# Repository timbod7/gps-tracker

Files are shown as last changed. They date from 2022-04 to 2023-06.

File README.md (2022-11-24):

A prototype GPS tracker and interface, intended primarily as an on-water speed display.

The [firmware](firmware) is written in rust. A water resistant enclosure is used with various 3d printed components. In order to ensure water resistance, the external switches magnetically couple to internal reed switches.

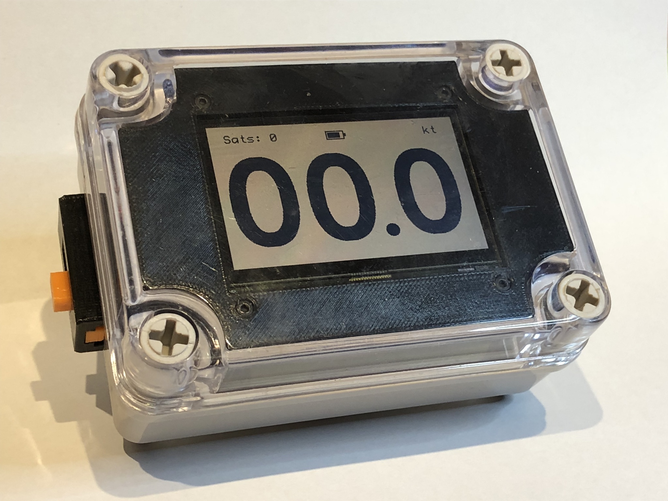
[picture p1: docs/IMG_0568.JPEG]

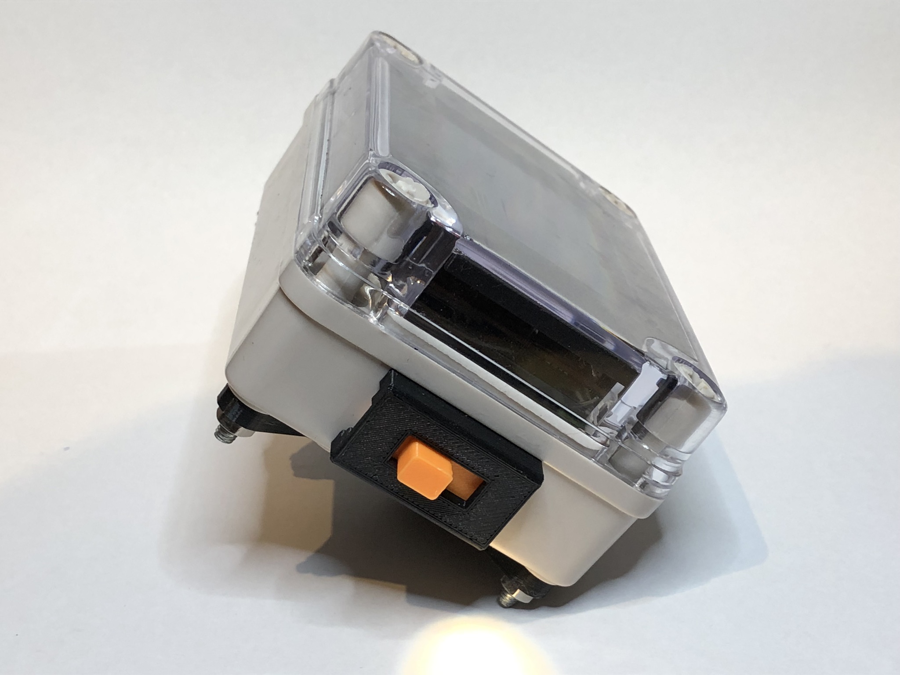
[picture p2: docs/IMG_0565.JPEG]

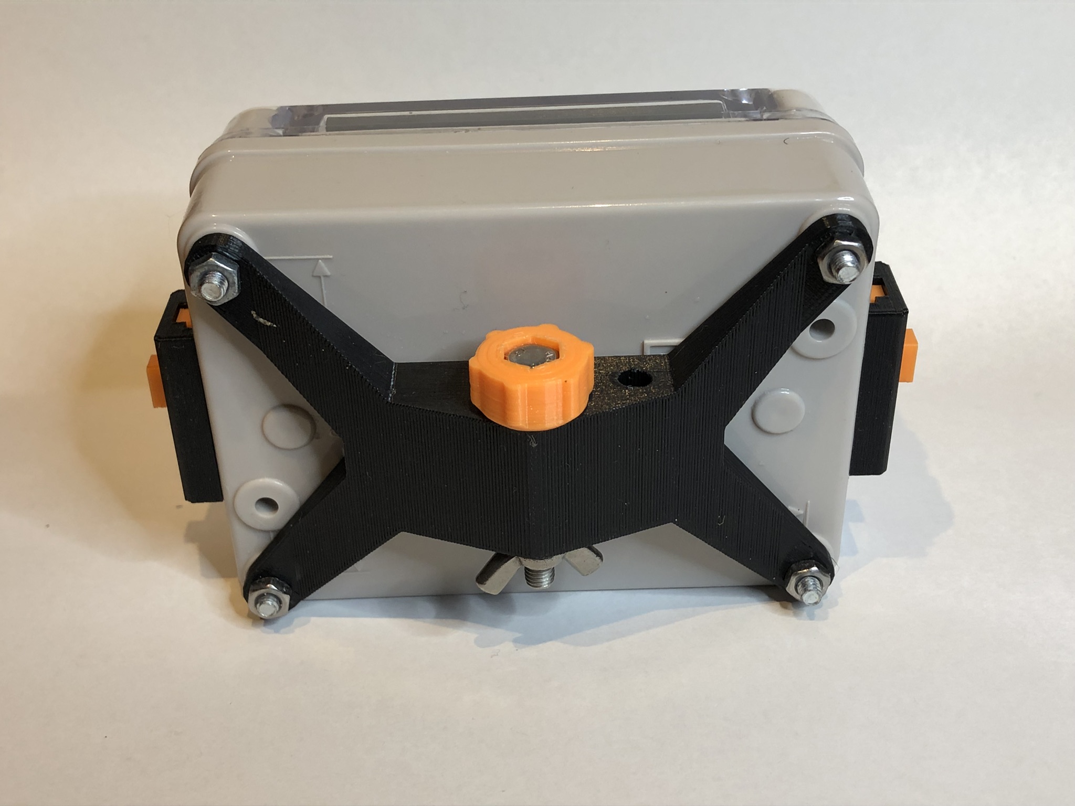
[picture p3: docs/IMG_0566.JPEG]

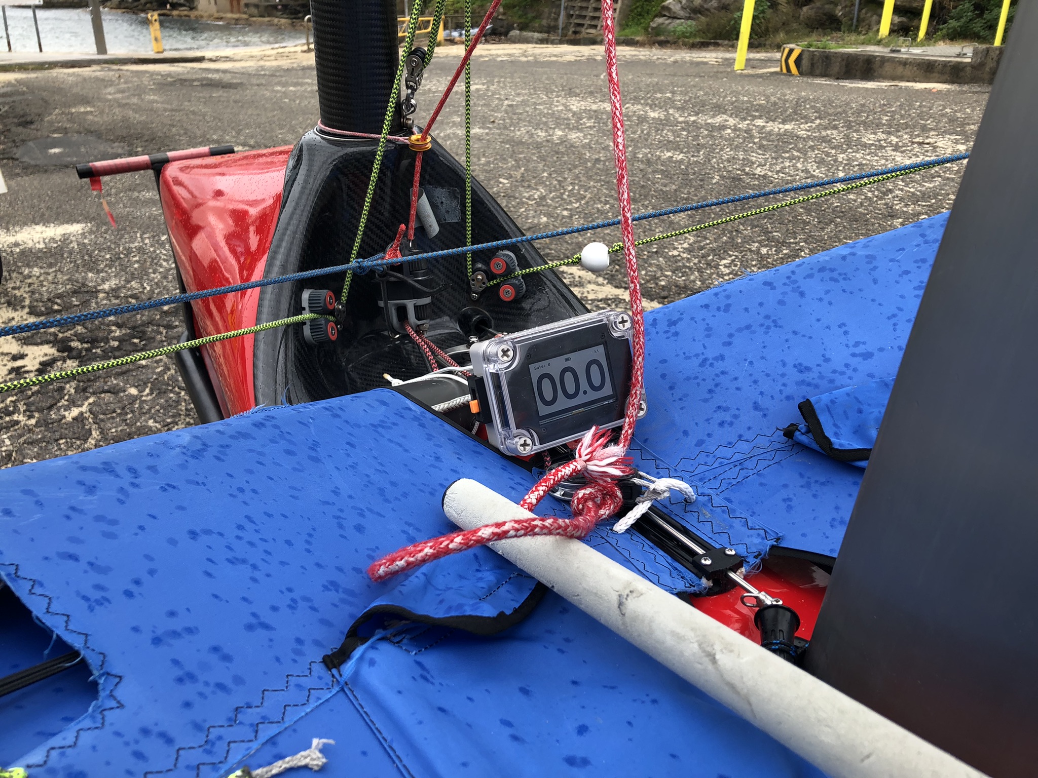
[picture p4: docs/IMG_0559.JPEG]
Installed


# Schematic

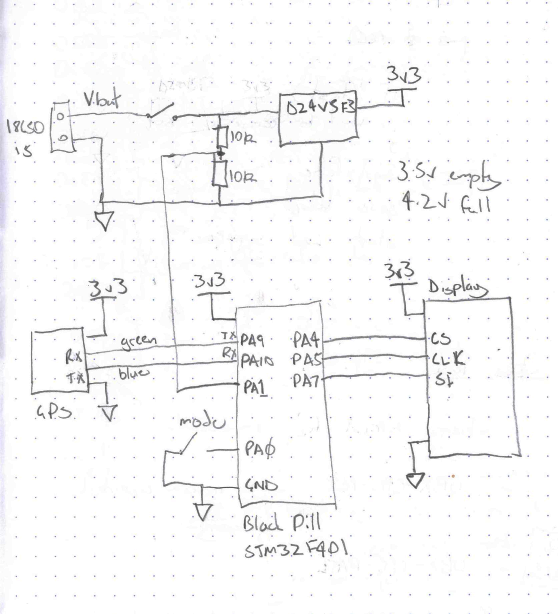
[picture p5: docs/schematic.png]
Schematic


# Components

## "Black Pill" STM32F411 board

https://core-electronics.com.au/stm32f411-blackpill-development-board-49034.html

## 3.3V LDO Regulator

https://core-electronics.com.au/pololu-3-3v-500ma-step-down-voltage-regulator-d24v5f3.html

## LS027B7DH01 LCD display 

https://core-electronics.com.au/adafruit-sharp-memory-display-breakout-2-7-400x240-monochrome.html

https://www.sharpsde.com/fileadmin/products/Displays/2016_SDE_App_Note_for_Memory_LCD_programming_V1.3.pdf

## GPS Receiver

[TBS M8.2 GPS Glonass][gps1]  (BN180 clone?)

## Waterproof Case

https://core-electronics.com.au/small-plastic-project-enclosure-weatherproof-with-clear-top.html

[gps1]: https://www.team-blacksheep.com/products/prod:tbs_m82_gps

# Firmware

To build the code, you need the `thumbv7em-none-eabihf` rust target:

```
rustup target add thumbv7em-none-eabihf
```

and cargo embed:

```
cargo install cargo-embed
```

On linux, add udev rules to ensure the stmlink device is accessible to all users:

```
$ cat /etc/udev/rules.d/50-stm-stlink.rules 
# STMicroelectronics ST-LINK/V2 
ATTRS{idVendor}=="0483", ATTRS{idProduct}=="3748", TAG+="uaccess"
$ sudo udevadm control --reload-rules
```

Then build and flash to the embedded board with:

```
cargo embed --release
```

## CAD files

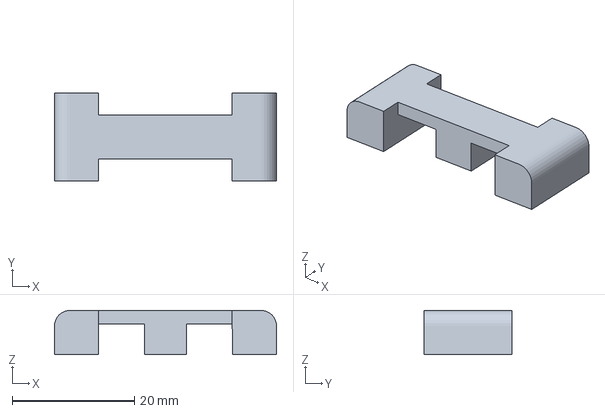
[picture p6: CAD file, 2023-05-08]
case/button/mount.3mf
36.3 x 14.4 x 7.20 mm

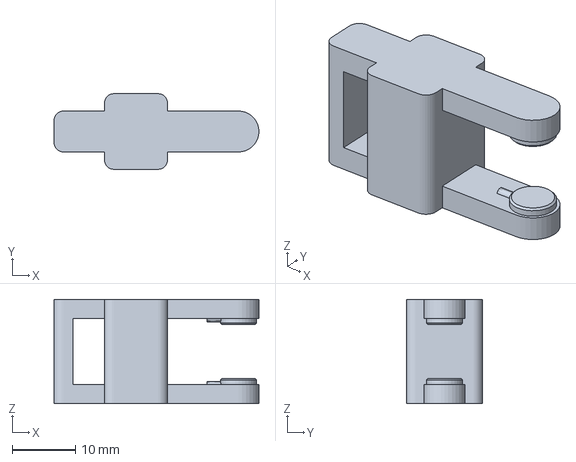
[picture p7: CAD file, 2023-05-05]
case/flip-switch/lever.3mf
32.5 x 12.0 x 16.5 mm

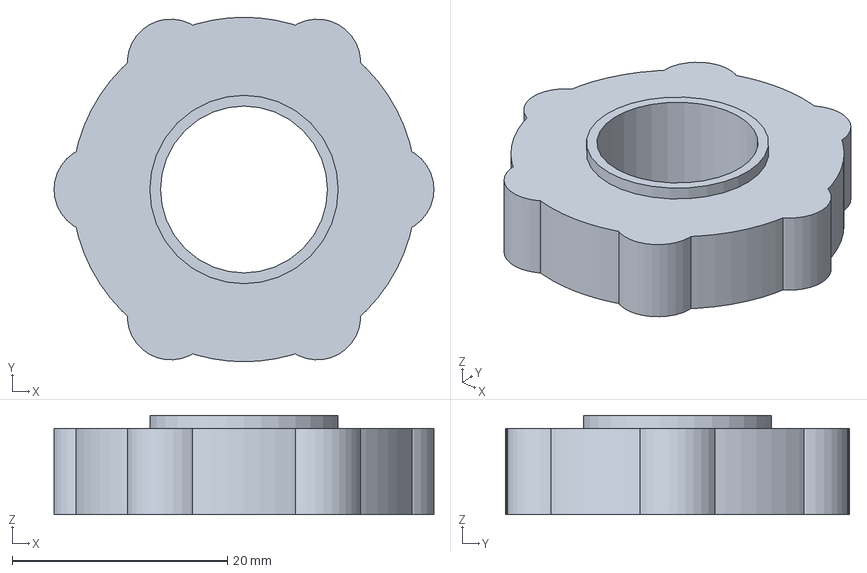
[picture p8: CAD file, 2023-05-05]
case/rotary-switch/knob.3mf
35.3 x 32.0 x 9.20 mm

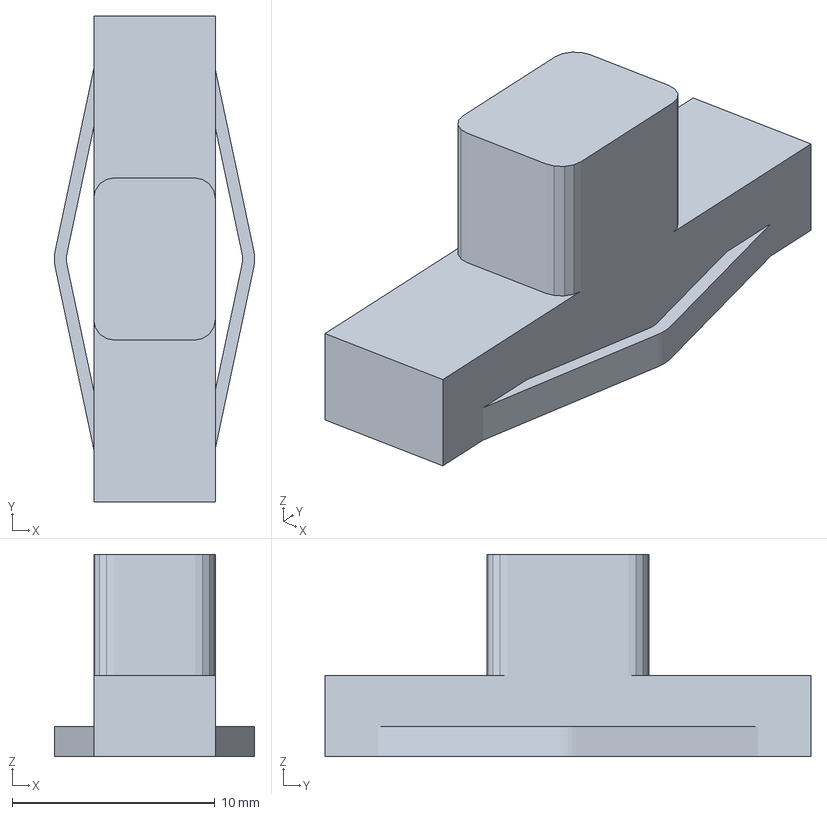
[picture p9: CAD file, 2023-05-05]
case/switch-actuator.3mf
9.90 x 24.0 x 10.0 mm

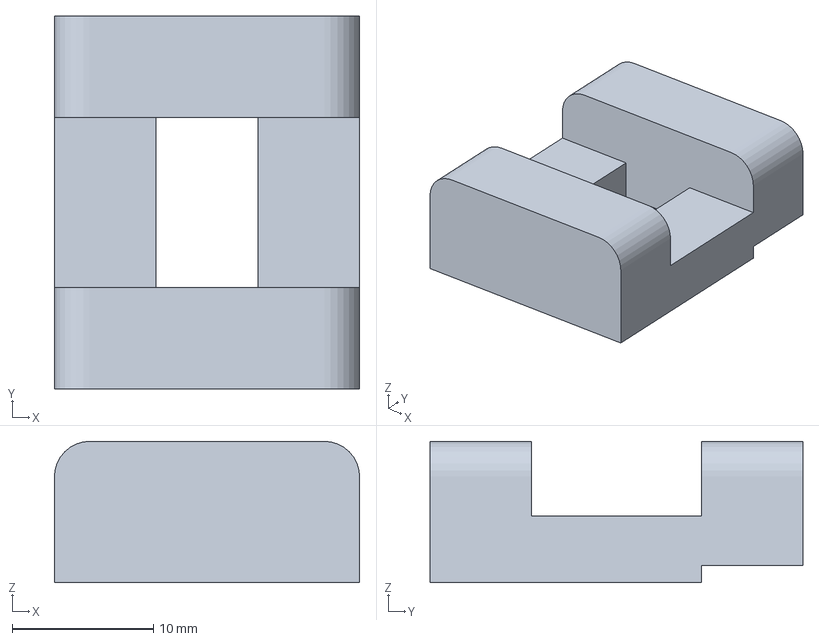
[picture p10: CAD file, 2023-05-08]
case/button/actuator.3mf
21.6 x 26.4 x 10.0 mm

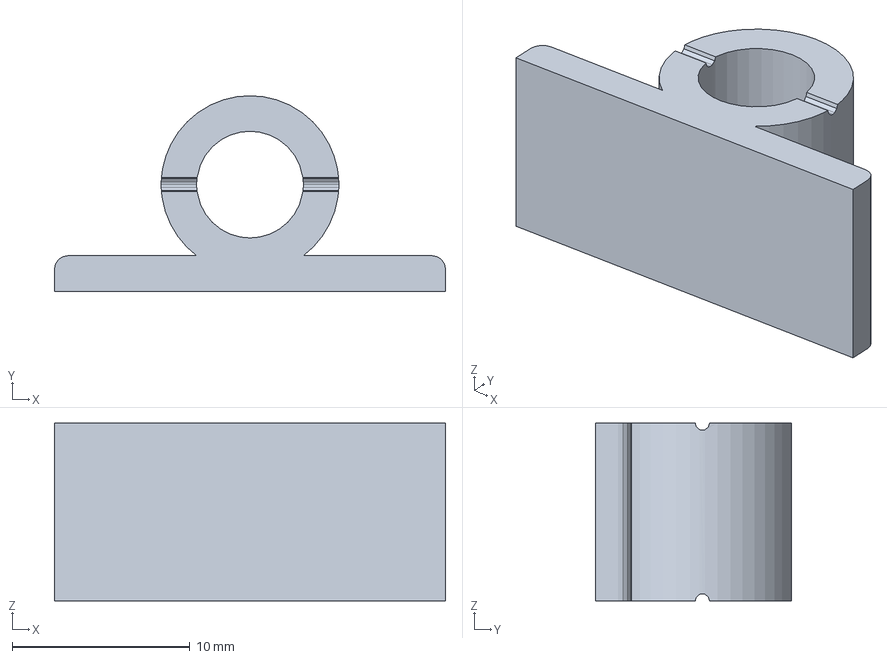
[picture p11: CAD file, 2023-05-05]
case/flip-switch/mount.3mf
22.0 x 11.0 x 10.0 mm

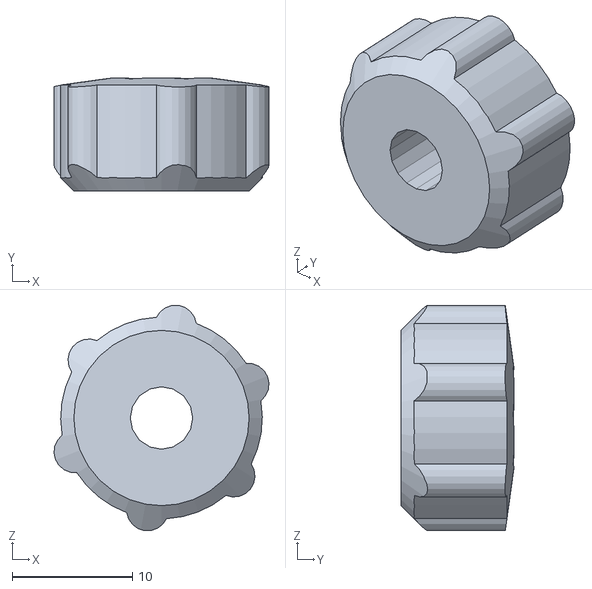
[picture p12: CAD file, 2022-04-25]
case/mount-knob.stl
17.9 x 9.43 x 18.8

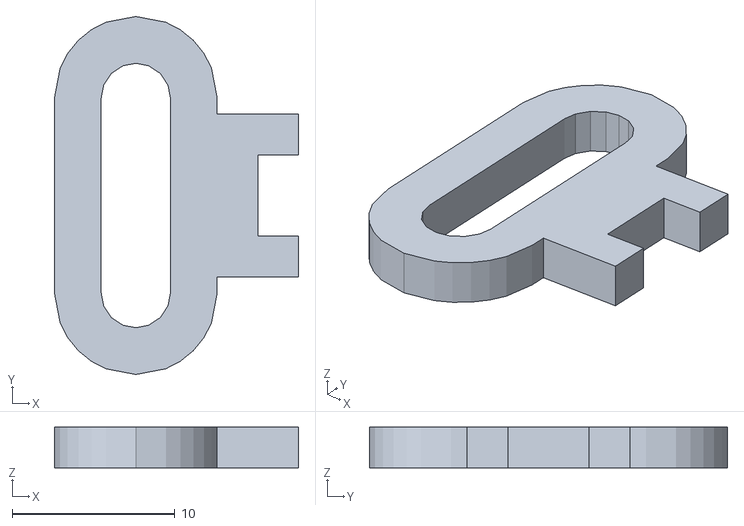
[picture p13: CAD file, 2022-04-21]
case/reed-switch-mount-holder.stl
15.0 x 22.0 x 2.50

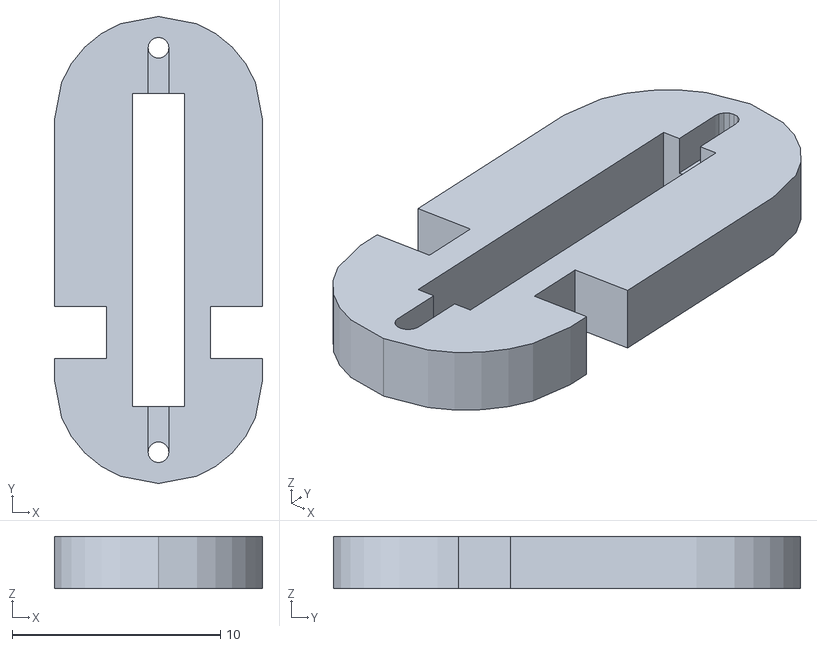
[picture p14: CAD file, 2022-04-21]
case/reed-switch-mount-2.stl
10.0 x 22.4 x 2.50

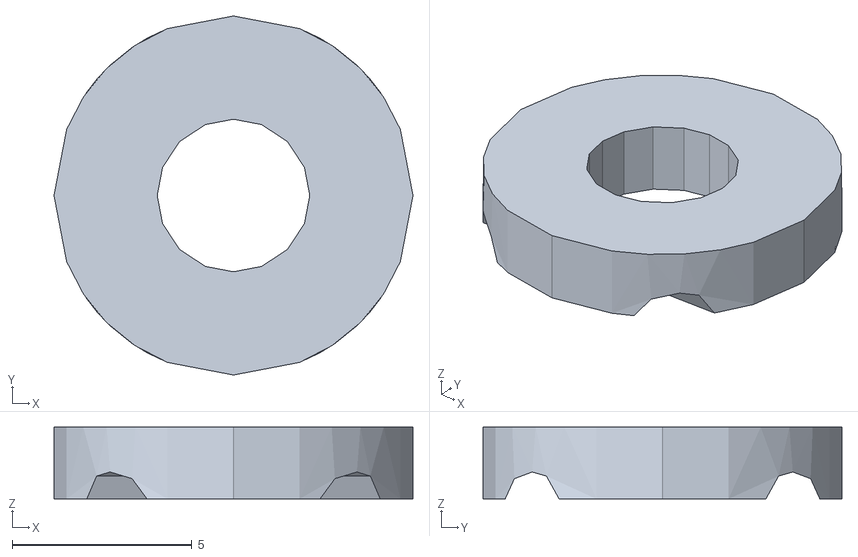
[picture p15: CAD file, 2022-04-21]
case/reed-switch-mount-clamp.stl
10.0 x 10.0 x 2.00

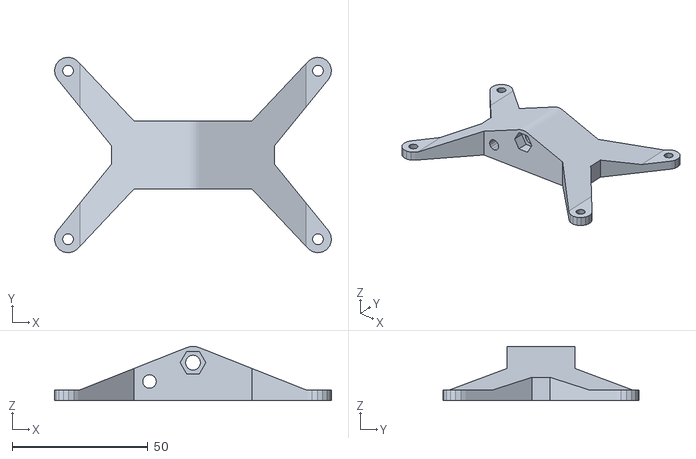
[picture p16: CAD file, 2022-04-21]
case/case-mount.stl
102.0 x 72.0 x 20.0

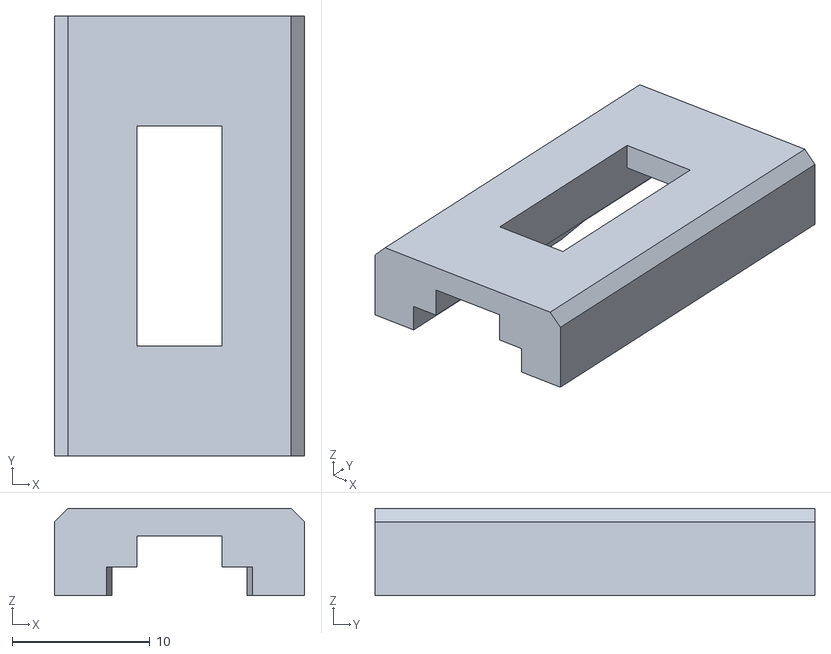
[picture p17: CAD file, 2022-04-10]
case/switch-body2.stl
18.2 x 32.0 x 6.35

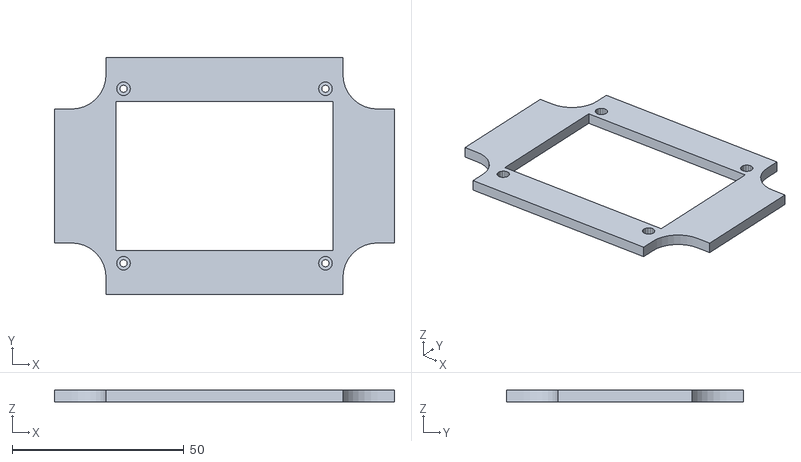
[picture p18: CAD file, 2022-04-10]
case/display-mount.stl
99.0 x 69.0 x 3.50

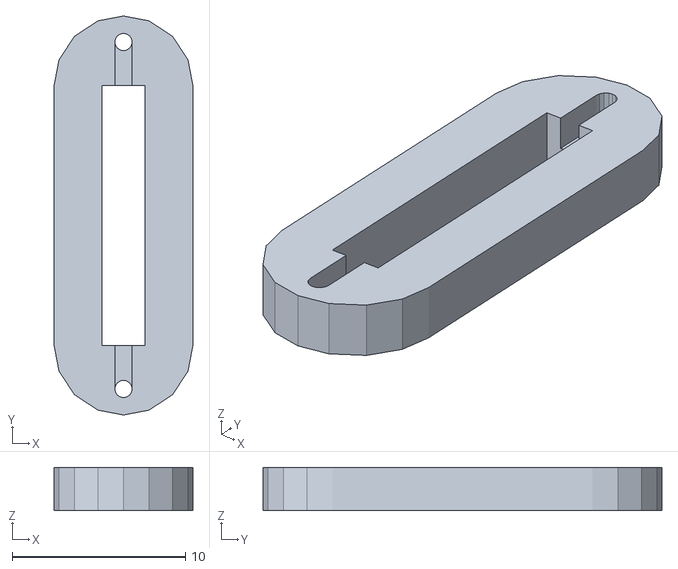
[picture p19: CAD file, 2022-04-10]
case/reed-switch-mount.stl
8.00 x 23.0 x 2.50

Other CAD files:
case/button/actuator.stl
case/button/mount.stl
case/flip-switch/lever.stl
case/flip-switch/mount.stl
case/rotary-switch/knob.stl
case/switch-actuator.stl

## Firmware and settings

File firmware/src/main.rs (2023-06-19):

#![no_main]
#![no_std]
mod debouncer;
mod gps;
mod layout;
mod memory_display;
mod screens;
#[allow(dead_code)]
mod u8writer;

// set the panic handler
extern crate panic_rtt_target;

#[rtic::app(device = stm32f4xx_hal::pac, dispatchers = [EXTI0])]
mod app {

    use embedded_hal::spi::{Mode, Phase, Polarity};
    use stm32f4xx_hal::{adc, gpio::NoPin, prelude::*, serial};

    use dwt_systick_monotonic::DwtSystick;

    use rtt_target::{rprintln, rtt_init_print};

    use nb::block;

    use crate::debouncer;
    use crate::memory_display;
    use crate::{gps::Gps, screens};

    type Display = crate::memory_display::MemoryDisplay<
        stm32f4xx_hal::spi::Spi<
            stm32f4xx_hal::pac::SPI1,
            (
                stm32f4xx_hal::gpio::Pin<
                    stm32f4xx_hal::gpio::Input<stm32f4xx_hal::gpio::Floating>,
                    'A',
                    5_u8,
                >,
                stm32f4xx_hal::gpio::NoPin,
                stm32f4xx_hal::gpio::Pin<
                    stm32f4xx_hal::gpio::Input<stm32f4xx_hal::gpio::Floating>,
                    'A',
                    7_u8,
                >,
            ),
            stm32f4xx_hal::spi::TransferModeNormal,
        >,
        stm32f4xx_hal::gpio::Pin<
            stm32f4xx_hal::gpio::Output<stm32f4xx_hal::gpio::PushPull>,
            'A',
            4_u8,
        >,
        stm32f4xx_hal::timer::Delay<stm32f4xx_hal::pac::TIM5, 1000000_u32>,
        12000_usize,
        240_usize,
    >;
    type Serial = stm32f4xx_hal::serial::Serial<
        stm32f4xx_hal::pac::USART1,
        (
            stm32f4xx_hal::gpio::Pin<
                stm32f4xx_hal::gpio::Alternate<stm32f4xx_hal::gpio::PushPull, 7_u8>,
                'A',
                9_u8,
            >,
            stm32f4xx_hal::gpio::Pin<
                stm32f4xx_hal::gpio::Alternate<stm32f4xx_hal::gpio::PushPull, 7_u8>,
                'A',
                10_u8,
            >,
        ),
        u8,
    >;
    type Key =
        stm32f4xx_hal::gpio::gpioa::PA0<stm32f4xx_hal::gpio::Input<stm32f4xx_hal::gpio::PullUp>>;
    type Adc = stm32f4xx_hal::adc::Adc<stm32f4xx_hal::pac::ADC1>;
    type Vin = stm32f4xx_hal::gpio::gpioa::PA1<stm32f4xx_hal::gpio::Analog>;
    type Led = stm32f4xx_hal::gpio::gpioc::PC13<
        stm32f4xx_hal::gpio::Output<stm32f4xx_hal::gpio::PushPull>,
    >;

    const MONO_HZ: u32 = 84_000_000; // 8 MHz

    #[monotonic(binds = SysTick, default = true)]
    type MyMono = DwtSystick<MONO_HZ>;

    #[shared]
    struct Shared {
        gps: Gps,
        vbat_mv: Option<u16>,
    }

    #[local]
    struct Local {
        serial: Serial,
        display: Display,
        key: Key,
        adc: Adc,
        vbatin: Vin,
        led: Led,
    }

    #[init()]
    fn init(cx: init::Context) -> (Shared, Local, init::Monotonics) {
        rtt_init_print!();
        rprintln!("init: START");

        // Take ownership over the raw flash and rcc devices and convert them into the corresponding
        // HAL structs
        let rcc = cx.device.RCC.constrain();

        let clocks = rcc.cfgr.use_hse(25.MHz()).sysclk(32.MHz()).freeze();

        let mut dcb = cx.core.DCB;
        let dwt = cx.core.DWT;
        let systick = cx.core.SYST;
        let mono: MyMono = DwtSystick::new(&mut dcb, dwt, systick, MONO_HZ);

        // Enable debugging in sleep modes so that stlink stays alive during wfi etc._
        // Remove this if/when power consumption is an issue.
        cx.device.DBGMCU.cr.write(|w| {
            w.dbg_sleep()
                .set_bit()
                .dbg_stop()
                .set_bit()
                .dbg_standby()
                .set_bit()
        });

        // configure the gpio ports
        let gpioa = cx.device.GPIOA.split();
        let gpioc = cx.device.GPIOC.split();
        let key = gpioa.pa0.into_pull_up_input();
        let vbatin = gpioa.pa1.into_analog();
        let mut led = gpioc.pc13.into_push_pull_output();

        // configure the display driver
        let cs = gpioa.pa4.into_push_pull_output();
        let spi = cx.device.SPI1.spi(
            (gpioa.pa5, NoPin, gpioa.pa7),
            Mode {
                phase: Phase::CaptureOnFirstTransition,
                polarity: Polarity::IdleLow,
            },
            2.MHz(),
            &clocks,
        );

        let delay = cx.device.TIM5.delay_us(&clocks);
        let mut display = memory_display::new_ls027b7dh01(spi, cs, delay);
        let layout = crate::layout::Layout::new();
        let font = layout.font_18();
        font.write_str(&mut display, font.char_point(0, 0), "booting...")
            .unwrap();
        display.refresh();

        // Configure the serial port for GPS data
        let tx = gpioa.pa9.into_alternate();
        let rx = gpioa.pa10.into_alternate();

        let mut serial: Serial = cx
            .device
            .USART1
            .serial((tx, rx), 9600.bps(), &clocks)
            .unwrap();
        let mut gps = Gps::new();

        rprintln!("init: gps");

        gps.init(&mut serial);
        led.set_low();
        serial.listen(serial::Event::Rxne);

        // Configure the ADC for battery voltage
        let adc_config = adc::config::AdcConfig::default();
        let adc = adc::Adc::adc1(cx.device.ADC1, true, adc_config);

        // Periodically read the battery voltage
        read_batv::spawn_after(250.millis()).unwrap();

        let shared = Shared {
            gps,
            vbat_mv: Some(0),
        };

        layout.clear(&mut display).unwrap();

        let local = Local {
            serial,
            display,
            key,
            adc,
            vbatin,
            led,
        };

        rprintln!("init: DONE");
        (shared, local, init::Monotonics(mono))
    }

    #[task(binds = USART1, shared=[gps], local=[serial])]
    fn usart1(mut cx: usart1::Context) {
        let ereceived: Result<u8, serial::Error> = block!(cx.local.serial.read());
        match ereceived {
            Result::Err(_e) => {
                rprintln!("usart1: error");
                cx.shared.gps.lock(|gps| gps.parse_clear());
            }
            Result::Ok(received) => {
                cx.shared.gps.lock(|gps| gps.parse_u8(received));
            }
        }
    }

    #[idle(shared=[gps, vbat_mv], local=[key,display])]
    fn idle(mut cx: idle::Context) -> ! {
        rprintln!("idle0: START");
        let mut screens = screens::Screens::new();
        let mut debounce = debouncer::Debouncer::new(2);

        screens.render(cx.local.display).unwrap();
        screens.update_vbat(0);

        cx.local.display.refresh();

        loop {
            let key = cx.local.key.is_high();
            match debounce.next(key) {
                Option::Some(debouncer::Transition::ToHigh) => {
                    screens.next_page(cx.local.display).unwrap();
                    cx.local.display.refresh();
                }
                _ => {}
            }

            // Fetch the updated gps values, if present

            let ogps = cx.shared.gps.lock(|gps| gps.take());

            let mut updated = false;
            if let Some(gps) = ogps {
                screens.update_gps(&gps);
                updated = true;
            }

            let ovbat_mv = cx.shared.vbat_mv.lock(|vbat_mv| vbat_mv.take());
            if let Some(vbat_mv) = ovbat_mv {
                screens.update_vbat(vbat_mv);
                updated = true;
            }

            if updated {
                screens.render(cx.local.display).unwrap();
            }
            cx.local.display.refresh();
        }
    }

    #[task(local=[adc,vbatin,led], shared=[vbat_mv])]
    fn read_batv(mut cx: read_batv::Context) {
        rprintln!("read_batv");

        // Read the pin voltage, and write it to the shared variable
        let sample = cx
            .local
            .adc
            .convert(cx.local.vbatin, adc::config::SampleTime::Cycles_480);
        let mv = cx.local.adc.sample_to_millivolts(sample) * 2;
        cx.shared.vbat_mv.lock(|vbat_mv| *vbat_mv = Some(mv));

        cx.local.led.toggle();
        read_batv::spawn_after(250.millis()).unwrap();
    }
}

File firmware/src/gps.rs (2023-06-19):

use embedded_hal::serial;
use nb::block;
use rtt_target::rprintln;

// How often we receive position data
const GPS_MESSAGE_MS: u16 = 500;

// How many speed samples we record to get an
// average over a second
const SPEED_SAMPLES: usize = 1000 / (GPS_MESSAGE_MS as usize);

// How many speed samples we record to get an
// average over 10 seconds
const SPEED_AVG_SAMPLES: usize = 10 * 1000 / (GPS_MESSAGE_MS as usize);

#[derive(Clone)]
pub struct GpsData {
    pub sat_in_use: u8,
    pub course: Option<f32>,
    pub speed: f32,
    pub max_speed: f32,
    pub avg_speed: f32,
    pub max_avg_speed: f32,
    pub distance_m: u32,
    pub hdop: Option<f32>,
    pub latitude: Option<f32>,
    pub longitude: Option<f32>,
    pub time: Option<GpsTime>,
}

#[derive(Clone, PartialEq, Eq)]
pub struct GpsTime {
    pub year: u16,
    pub month: u8,
    pub day: u8,
    pub hour: u8,
    pub min: u8,
    pub sec: u8,
}

pub struct Gps {
    parser: ublox::Parser<GpsBuffer>,

    output: GpsData,

    updated: Option<()>, // atomic bool???

    speed_samples: AverageBuffer<SPEED_SAMPLES>,
    avg_speed_samples: AverageBuffer<SPEED_AVG_SAMPLES>,
}

impl Gps {
    pub fn new() -> Gps {
        let buf = GpsBuffer::new();
        let parser = ublox::Parser::new(buf);

        Gps {
            parser,
            output: GpsData {
                sat_in_use: 0,
                course: None,
                hdop: None,
                latitude: None,
                longitude: None,
                speed: 0f32,
                distance_m: 0,
                time: None,
                max_speed: 0f32,
                avg_speed: 0f32,
                max_avg_speed: 0f32,
            },

            updated: Option::Some(()),
            speed_samples: AverageBuffer::new(),
            avg_speed_samples: AverageBuffer::new(),
        }
    }

    pub fn init<S: serial::Write<u8> + serial::Read<u8>>(&mut self, serial: &mut S) {
        loop {
            // Wait a bit to give the GPS some time for a cold start
            cortex_m::asm::delay(16_000_000);

            match self.init0(serial) {
                Ok(_) => break,
                Err(_) => {}
            }

            // Reset the parser
            let buf = GpsBuffer::new();
            self.parser = ublox::Parser::new(buf);
        }
    }

    pub fn init0<S: serial::Write<u8> + serial::Read<u8>>(
        &mut self,
        serial: &mut S,
    ) -> Result<(), ()> {
        use ublox::*;
        rprintln!("gps: init");

        // Configure to talk UBX
        rprintln!("gps: use UBX 1/2");
        let msg = CfgPrtUartBuilder {
            portid: UartPortId::Uart1,
            reserved0: 0,
            tx_ready: 0,
            mode: UartMode::new(DataBits::Eight, Parity::None, StopBits::One),
            baud_rate: 9600,
            in_proto_mask: InProtoMask::all(),
            out_proto_mask: OutProtoMask::UBLOX,
            flags: 0,
            reserved5: 0,
        }
        .into_packet_bytes();
        self.serial_write(serial, &msg);

        // Wait a bit
        cortex_m::asm::delay(16_000_000);
        // Throw away rx contents
        let _ = serial.read();

        // Send the message again
        rprintln!("gps: use UBX 2/2");
        self.serial_write(serial, &msg);

        rprintln!("gps: awaiting ack for UBX");
        self.serial_wait_for_ack::<S, CfgPrtUart>(serial)?;

        // Set the measurement/nav rate to 2 Hz
        rprintln!("gps: set rate to 2Hz");
        let msg = CfgRateBuilder {
            measure_rate_ms: GPS_MESSAGE_MS,
            nav_rate: 1,
            time_ref: AlignmentToReferenceTime::Utc,
        }
        .into_packet_bytes();
        self.serial_write(serial, &msg);
        self.serial_wait_for_ack::<S, CfgRate>(serial)?;

        // Enable the packets required
        rprintln!("gps: enable NavPosVelTime");
        let msg = CfgMsgAllPortsBuilder::set_rate_for::<NavPosVelTime>([0, 1, 0, 0, 0, 0])
            .into_packet_bytes();
        self.serial_write(serial, &msg);
        self.serial_wait_for_ack::<S, CfgMsgAllPorts>(serial)?;
        rprintln!("gps: enable NavOdo");
        let msg =
            CfgMsgAllPortsBuilder::set_rate_for::<NavOdo>([0, 1, 0, 0, 0, 0]).into_packet_bytes();
        self.serial_write(serial, &msg);
        self.serial_wait_for_ack::<S, CfgMsgAllPorts>(serial)?;

        // Send a packet request for the MonVer packet
        rprintln!("gps: request MonVer");
        let msg = UbxPacketRequest::request_for::<MonVer>().into_packet_bytes();
        self.serial_write(serial, &msg);

        Ok(())
    }

    fn serial_write<S: serial::Write<u8>>(&mut self, serial: &mut S, msg: &[u8]) {
        for b in msg {
            let _ = block!(serial.write(*b));
        }
        let _ = block!(serial.flush());
    }

    fn serial_wait_for_ack<S: serial::Read<u8>, T: ublox::UbxPacketMeta>(
        &mut self,
        serial: &mut S,
    ) -> Result<(), ()> {
        #[derive(PartialEq)]
        enum State {
            Waiting,
            Found,
            Failed,
        }

        let mut state = State::Waiting;
        while state == State::Waiting {
            let ec = block!(serial.read());
            match ec {
                Result::Err(_e) => {
                    rprintln!("rx fail waiting for ack");
                    state = State::Failed;
                }
                Result::Ok(c) => {
                    let buf = [c];
                    let mut it = self.parser.consume(&buf);
                    loop {
                        match it.next() {
                            Some(Ok(ublox::PacketRef::AckAck(ack))) => {
                                if ack.class() == T::CLASS && ack.msg_id() == T::ID {
                                    state = State::Found;
                                } else {
                                    rprintln!("ignoring other ack");
                                    state = State::Failed;
                                }
                            }
                            Some(Ok(_)) => {
                                rprintln!("ignoring other message");
                                state = State::Failed;
                            }
                            Some(Err(_)) => {
                                rprintln!("ignoring parse error");
                                state = State::Failed;
                            }
                            None => {
                                break;
                            }
                        }
                    }
                }
            }
        }
        if state == State::Found {
            Ok(())
        } else {
            Err(())
        }
    }

    pub fn parse_clear(&mut self) {
        rprintln!("gps: parse clear");
        let buf = GpsBuffer::new();
        self.parser = ublox::Parser::new(buf);
    }

    pub fn parse_u8(&mut self, received: u8) {
        let nb = [received; 1];
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

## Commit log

2022-03-25 Switch to rtic 1.0
2022-03-25 Added a battery % icon
2022-04-10 Case components
    [display-mount.stl, reed-switch-mount.stl, switch-actuator.stl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]
2022-04-15 Added case mount
    [case-mount.stl]
2022-04-21 Case improvements
    [case-mount.stl, reed-switch-mount-2.stl, reed-switch-mount-clamp.stl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]
2022-04-25 Added screw mount knob
    [mount-knob.stl]
2022-12-12 Don't enable interrupts until the gps device is initialized
2022-12-12 Retry on gps init failure
    [gps.rs]
2022-12-12 add a boot delay and message to fix some issue at power on
    [main.rs]
2022-12-19 hopefully a more reliable gps power up sequence
2023-05-05 assorted case changes
    [actuator.stl, knob.3mf, knob.stl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]
2023-05-08 tweaked magnetic button
    [actuator.3mf, actuator.stl, mount.3mf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]
